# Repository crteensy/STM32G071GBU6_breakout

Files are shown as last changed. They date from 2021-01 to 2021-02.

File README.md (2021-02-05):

# STM32G071GBU6_breakout
Breakout board for the STM32G071GBU6

## Partially tested
I've built one of these and measured:

- (unpowered) no shorts
- (unpowered) diode between I/O and ground
- (powered) 3V3 output is fine

Reset was not tested.

I didn't have the exact switch (KMR2) but one with an extra ground tab (KMR2xxG) but you that's not a problem - the ground tab doesn't touch antything.

Flashing a binary with st-flash worked too.

The breakout board was not tested with external circuitry yet.

## Short description

A very simple breakout board for the STM32G071GBU6:

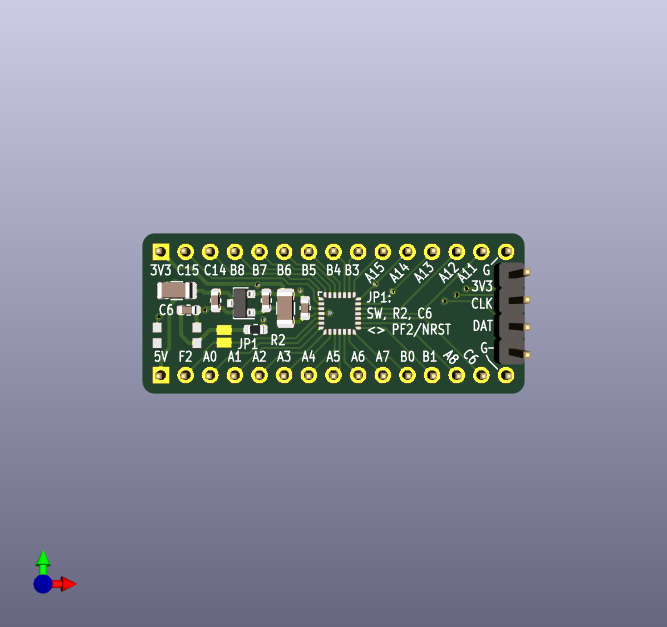
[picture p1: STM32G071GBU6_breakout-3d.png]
3D view


Reset circuitry (pull-up, cap, push button to GND) can be connected to PF2/NRST by closing solder jumper JP1.

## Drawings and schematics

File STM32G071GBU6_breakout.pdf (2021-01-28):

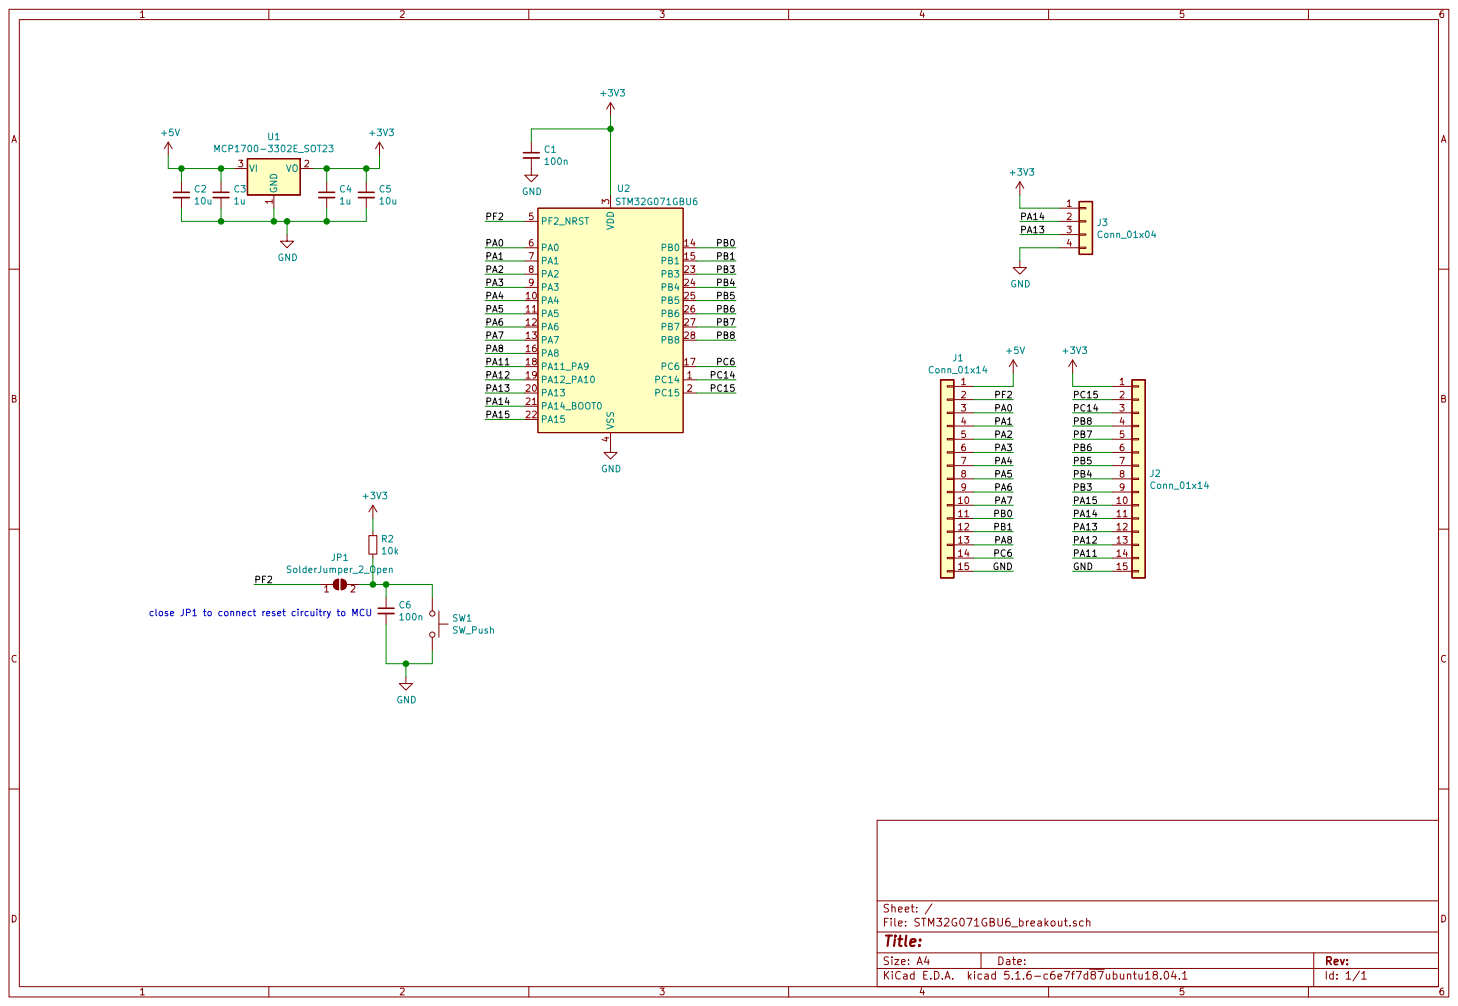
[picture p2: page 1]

close JP1 to connect reset circuitry to MCU

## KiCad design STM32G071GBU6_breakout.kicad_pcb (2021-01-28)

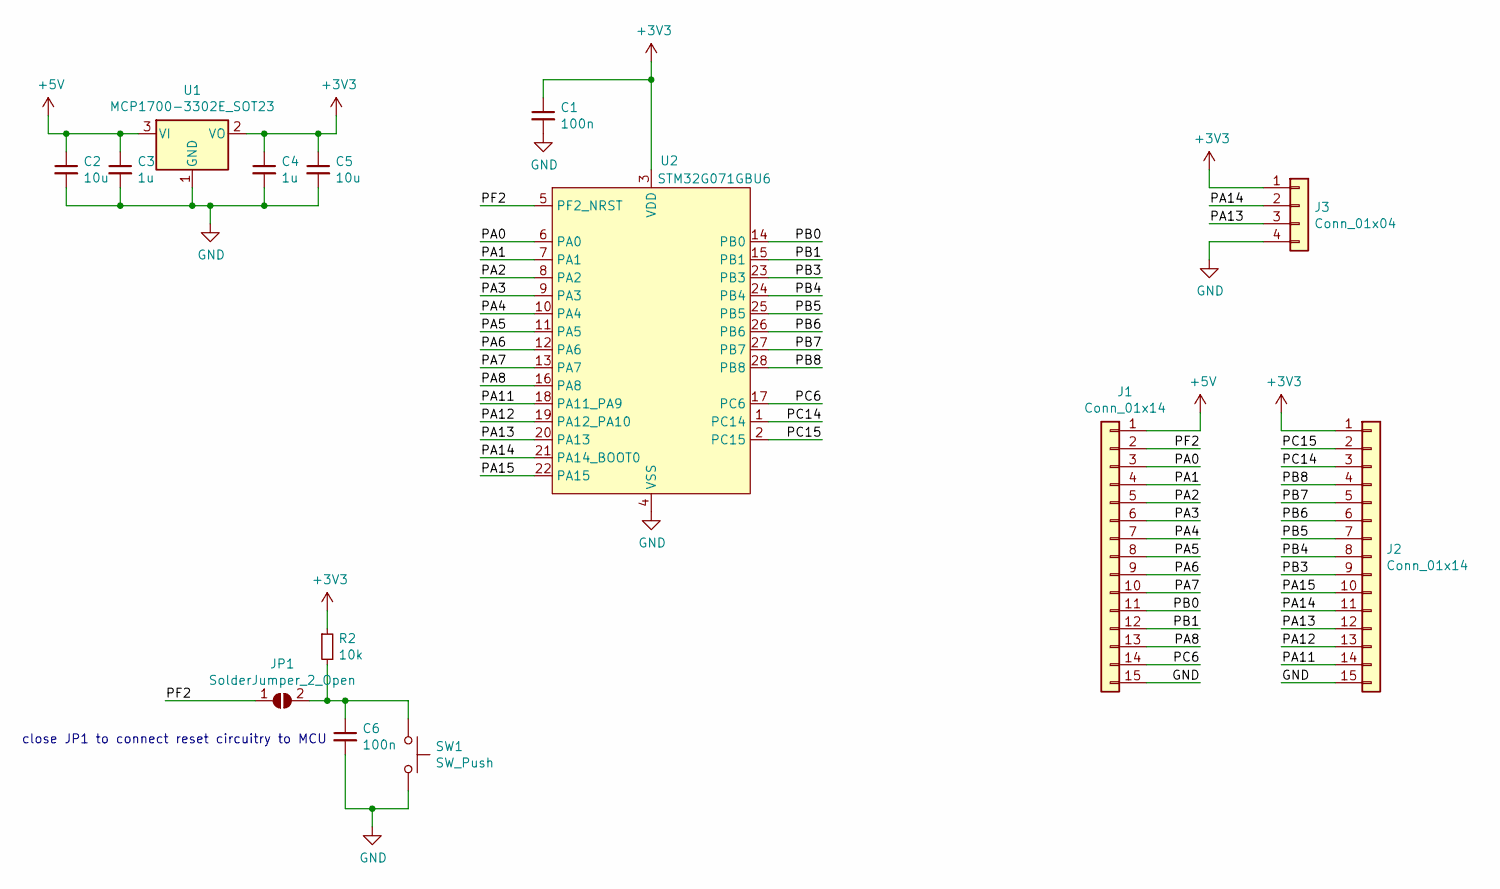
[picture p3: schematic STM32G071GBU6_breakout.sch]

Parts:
C1, C6: 100n; C_0603_1608Metric
C2, C5: 10u; C_1206_3216Metric
C3, C4: 1u; C_0603_1608Metric
J1, J2: Conn_01x14; PinHeader_1x15_P2.54mm_Vertical
J3: Conn_01x04; PinHeader_1x04_P2.54mm_Vertical
JP1: SolderJumper_2_Open; SolderJumper-2_P1.3mm_Open_Pad1.0x1.5mm
R2: 10k; R_0603_1608Metric
SW1: SW_Push; SW_Push_1P1T_NO_CK_KMR2
U1: MCP1700-3302E_SOT23; SOT-23
U2: STM32G071GBU6; UFQFPN28

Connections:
+3V3: C1.1, C4.1, C5.1, J2.1, J3.1, R2.1, U1.2 (VO), U2.3 (VDD)
+5V: C2.1, C3.1, J1.1, U1.3 (VI)
/PA0: J1.3, U2.6 (PA0)
/PA1: J1.4, U2.7 (PA1)
/PA2: J1.5, U2.8 (PA2)
/PA3: J1.6, U2.9 (PA3)
/PA4: J1.7, U2.10 (PA4)
/PA5: J1.8, U2.11 (PA5)
/PA6: J1.9, U2.12 (PA6)
/PA7: J1.10, U2.13 (PA7)
/PA8: J1.13, U2.16 (PA8)
/PA11: J2.14, U2.18 (PA11_PA9)
/PA12: J2.13, U2.19 (PA12_PA10)
/PA13: J2.12, J3.3, U2.20 (PA13)
/PA14: J2.11, J3.2, U2.21 (PA14_BOOT0)
/PA15: J2.10, U2.22 (PA15)
/PB0: J1.11, U2.14 (PB0)
/PB1: J1.12, U2.15 (PB1)
/PB3: J2.9, U2.23 (PB3)
/PB4: J2.8, U2.24 (PB4)
/PB5: J2.7, U2.25 (PB5)
/PB6: J2.6, U2.26 (PB6)
/PB7: J2.5, U2.27 (PB7)
/PB8: J2.4, U2.28 (PB8)
/PC6: J1.14, U2.17 (PC6)
/PC14: J2.3, U2.1 (PC14)
/PC15: J2.2, U2.2 (PC15)
/PF2: J1.2, JP1.1 (A), U2.5 (PF2_NRST)
GND: C1.2, C2.2, C3.2, C4.2, C5.2, C6.2, J1.15, J2.15, J3.4, SW1.2, U1.1 (GND), U2.4 (VSS)
unnamed: C6.1, JP1.2 (B), R2.2, SW1.1

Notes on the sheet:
close JP1 to connect reset circuitry to MCU

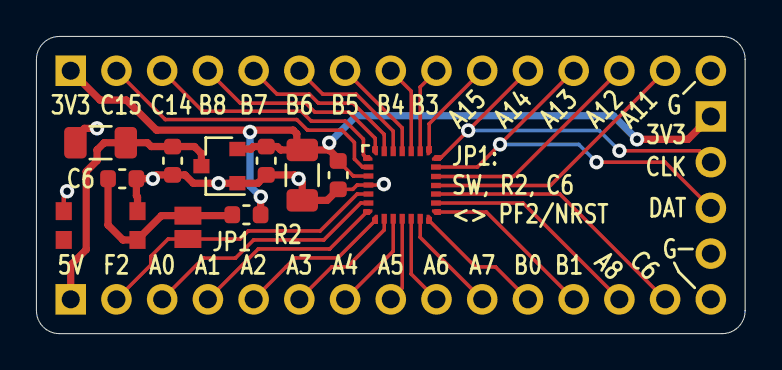
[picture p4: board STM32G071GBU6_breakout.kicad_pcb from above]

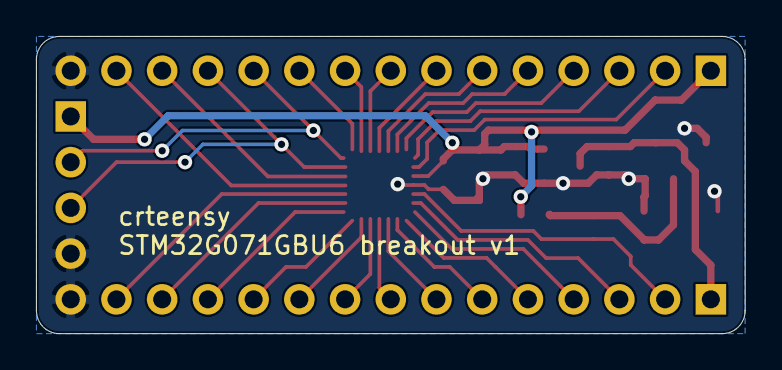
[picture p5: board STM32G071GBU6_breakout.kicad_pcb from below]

Board: 2 copper layers, 39.4 x 16.5 mm, 14 parts (2 on the bottom side), 30 nets.

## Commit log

2021-01-28 initial commit, board not tested yet
    [STM32G071GBU6_breakout.kicad_pcb, STM32G071GBU6_breakout.sch]
2021-01-28 change SW to KMR2
    [STM32G071GBU6_breakout.kicad_pcb, STM32G071GBU6_breakout.sch]
2021-02-05 update readme: board partially tested
